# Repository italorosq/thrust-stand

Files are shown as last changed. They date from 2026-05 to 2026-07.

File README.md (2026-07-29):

# thrust-stand




## 📋 Sobre

Sistema embarcado baseado em ESP32 para monitoramento de testes estáticos de motores de foguetes, com aquisição de dados de empuxo e pressão em tempo real, armazenamento em cartão SD e comunicação via Serial/Bluetooth.

## 🚀 Quick Start

1. Clone o repositório

```bash
git clone https://github.com/ViniciusCMB/thrust-stand.git
```

2. Configure o hardware conforme [esquemático](./docs/HARDWARE.md)
3. Carregue o firmware

## 📁 Estrutura do Projeto

```
├── 📂 docs/              # Documentação técnica detalhada
├── 📂 extras/            # Códigos extras utilizados
├── 📂 firmware/          # Código do microcontrolador ESP32
├── 📂 hardware/          # Esquemáticos, PCBs e lista de componentes
├── 📂 software/          # Ferramentas de análise e interface
└── 📂 tests/             # Testes unitários e de integração
```

## 🔧 Pré-requisitos

- Hardware: ESP32 DevKit V1, célula de carga + HX711, sensor de pressão (com divisor resistivo), módulo microSD (SPI), botão tátil (`GPIO33` para TARE), LED com resistor de limitação, buzzer
- Software: Arduino IDE 2.0+
- Bibliotecas: ver `docs/FIRMWARE.md`

## 📖 Documentação

- [Esquemático e Montagem](./docs/HARDWARE.md)
- [Firmware e Arquitetura](./docs/FIRMWARE.md)
- [Protocolos e API](./docs/API.md)
- [Troubleshooting](./docs/TROUBLESHOOTING.md)

## 🎯 Funcionalidades

- ✅ Aquisição de dados de empuxo e pressão em tempo real
- ✅ Armazenamento em cartão SD com arquivos sequenciais
- ✅ Controle local por botões (TARE e novo arquivo)
- ✅ LED de status de gravação no SD
- ✅ Comunicação (Serial, Bluetooth)
- ✅ Calibração persistente da célula de carga

## 📊 Dados de Teste

Os dados de testes estáticos de motores específicos são armazenados no repositório dedicado:
[motor](https://github.com/Serra-Rocketry/motor)

Este repositório (thrust-stand) contém apenas o sistema de aquisição. Os dados coletados durante os testes devem ser commitados no repositório `motor`.

## 🤝 Contribuindo

Este projeto segue as [Boas Práticas da Serra Rocketry](https://github.com/Serra-Rocketry/best-practices). Para contribuir:

1. Fork o projeto
2. Crie uma branch para sua feature (`git checkout -b feature/AmazingFeature`)
3. Commit suas mudanças (`git commit -m 'Add some AmazingFeature'`)
4. Push para a branch (`git push origin feature/AmazingFeature`)
5. Abra um Pull Request

## ✨ Autores

- Equipe Serra Rocketry - Desenvolvimento e documentação
- Contribuidores - [Lista de contribuidores]()

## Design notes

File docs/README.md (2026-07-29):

# 📚 Documentação Técnica - Sistema de Teste Estático

Esta documentação reúne o necessário para montagem, calibração, operação e troubleshooting do sistema baseado em ESP32.

## 🗂️ Estrutura da Documentação

### 1. Guia de Instalação

- Requisitos de hardware e software
- Configuração do ambiente
- Primeira execução

### 2. [Hardware](./HARDWARE.md)

- Lista de componentes (BOM)
- Mapeamento de pinos e conexões
- Função dos botões e do LED

### 3. [Firmware](./FIRMWARE.md)

- Arquitetura e fluxo de aquisição
- Calibração da célula de carga
- Sistema de arquivos e armazenamento

### 4. [API e Protocolos](./API.md)

- Comandos seriais
- Controles físicos
- Exemplos de interação

### 5. [Troubleshooting](./TROUBLESHOOTING.md)

- Problemas comuns e diagnóstico rápido
- Procedimentos de correção

### 6. [Evolução da Caixa](./EVOLUÇÃO_CAIXA.md)

- Histórico das 3 versões da estrutura física
- Comparativo de materiais e design

### 7. [V3 Detalhes](./V3_DETALHES.md)

- Especificações da bancada v3
- Célula de carga, guia linear, resolução

## 📊 Diagramas Técnicos

Arquitetura do sistema:

```
[Sensores] -> [ESP32] -> [Armazenamento] -> [Comunicação]
    |            |             |               |
 Célula/HX711  Process.      microSD        Serial/BT
 Pressão       Dados         Arquivo CSV    Monitoramento
```

Fluxo de dados:

```mermaid
graph TD;
    A[Sensores] --> B[Aquisição];
    B --> C[Processamento];
    C --> D[Armazenamento SD];
    C --> E[Transmissão];
    D --> F[Arquivo CSV];
    E --> G[Serial];
    E --> H[Bluetooth];
```

## 🛠️ Recursos Técnicos

### Especificações do Sistema

- Microcontrolador: ESP32
- Sensores: célula de carga (HX711) e sensor de pressão analógico
- Armazenamento: cartão SD (SPI), com fallback para LittleFS
- Comunicação: Serial USB e Bluetooth
- Controles físicos:
  - Botão `GPIO33`: TARE
  - LED `GPIO19`: aceso durante gravação no SD
  - Buzzer `GPIO32`: sinalização

### Formatos de Dados

- Logs: CSV (`Tempo,Empuxo,Pressao`)
- Configuração: `Preferences` (fator de calibração)
- Comunicação: comandos por texto

## 🤝 Contribuindo para a Documentação

1. Reporte inconsistências encontradas
2. Proponha melhorias de texto e organização
3. Abra PR com correções objetivas

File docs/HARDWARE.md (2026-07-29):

# 🔌 Hardware - Sistema de Teste Estático

## 📋 Visão Geral do Sistema

Sistema embarcado baseado em ESP32 para aquisição de empuxo e pressão em testes estáticos de motores de foguetes, com gravação local de dados no cartão SD e telemetria via Serial/Bluetooth.

Controles físicos do esquemático atual:

- `GPIO33`: botão para TARE (zerar a célula de carga)
- `GPIO19`: LED de indicador de funcionamento (aceso durante gravação no SD)
- `GPIO32`: buzzer de sinalização

## 🧩 Lista de Componentes (BOM)

| Componente | Quantidade | Especificações |
| --- | --- | --- |
| ESP32 DevKit V1 | 1 | 30/38 pinos, WiFi/BT |
| Célula de carga | 1 | Compatível com HX711 |
| Módulo HX711 | 1 | ADC 24 bits para célula de carga |
| Sensor de pressão | 1 | 0-10 MPa, saída analógica 0.5-4.5V |
| Módulo microSD | 1 | Interface SPI |
| LED | 1 | 5mm, vermelho |
| Botão tátil (TARE) | 1 | 6x6mm |
| Buzzer | 1 | Ativo, 5V |
| Resistores do divisor | 2 | 2.2kΩ e 3.3kΩ |
| Resistor do LED | 1 | 220Ω (valor típico) |
| Fonte de alimentação | 1 | 5V 2A (mínimo recomendado) |

## 🔄 Mapeamento de Conexões

| ESP32 | Função no sistema |
| ----- | --- |
| `GPIO4`  | HX711 `DT` |
| `GPIO18` | HX711 `SCK` |
| `GPIO35` | Entrada do sensor de pressão (via divisor resistivo) |
| `GPIO5`  | microSD `CS` |
| `GPIO27` | microSD `MOSI` |
| `GPIO23` | microSD `MISO` |
| `GPIO25` | microSD `SCK` |
| `GPIO19` | LED de gravação |
| `GPIO32` | Buzzer |
| `GPIO33` | Botão TARE |
| `VIN` | Alimentação 5V dos módulos |
| `GND` | Terra comum |

Observações de ligação:

- Botão: um terminal no `GPIO33` e o outro no `GND`.
- LED: ligado ao `GPIO19` com resistor em série.
- Buzzer: ligado ao `GPIO32`.
- Sensor de pressão: saída analógica passa por divisor resistivo antes de chegar ao `GPIO35`.

## 🛠️ Procedimento de Montagem

1. Preparação dos componentes

- Verifique todos os itens da BOM
- Teste ESP32 e cartão SD separadamente antes da montagem final

2. Sequência recomendada

- Conecte alimentação (`VIN` e `GND`)
- Conecte HX711 e célula de carga
- Conecte módulo microSD (SPI)
- Conecte sensor de pressão com divisor resistivo
- Conecte LED de status
- Conecte o botão (`GPIO33`)

3. Divisor resistivo para o sensor de pressão

```
Vsensor (0.5-4.5V) --- R1 (2.2kΩ) --- GPIO35
                         |
                        R2 (3.3kΩ)
                         |
                        GND
```

Cálculo do divisor:

```
Vout = Vsensor * (R2 / (R1 + R2))

# Exemplo
Vout_max = 4.5V * (3300 / (2200 + 3300)) = 2.7V
```

## 📷 Foto de Referência

Montagem completa:

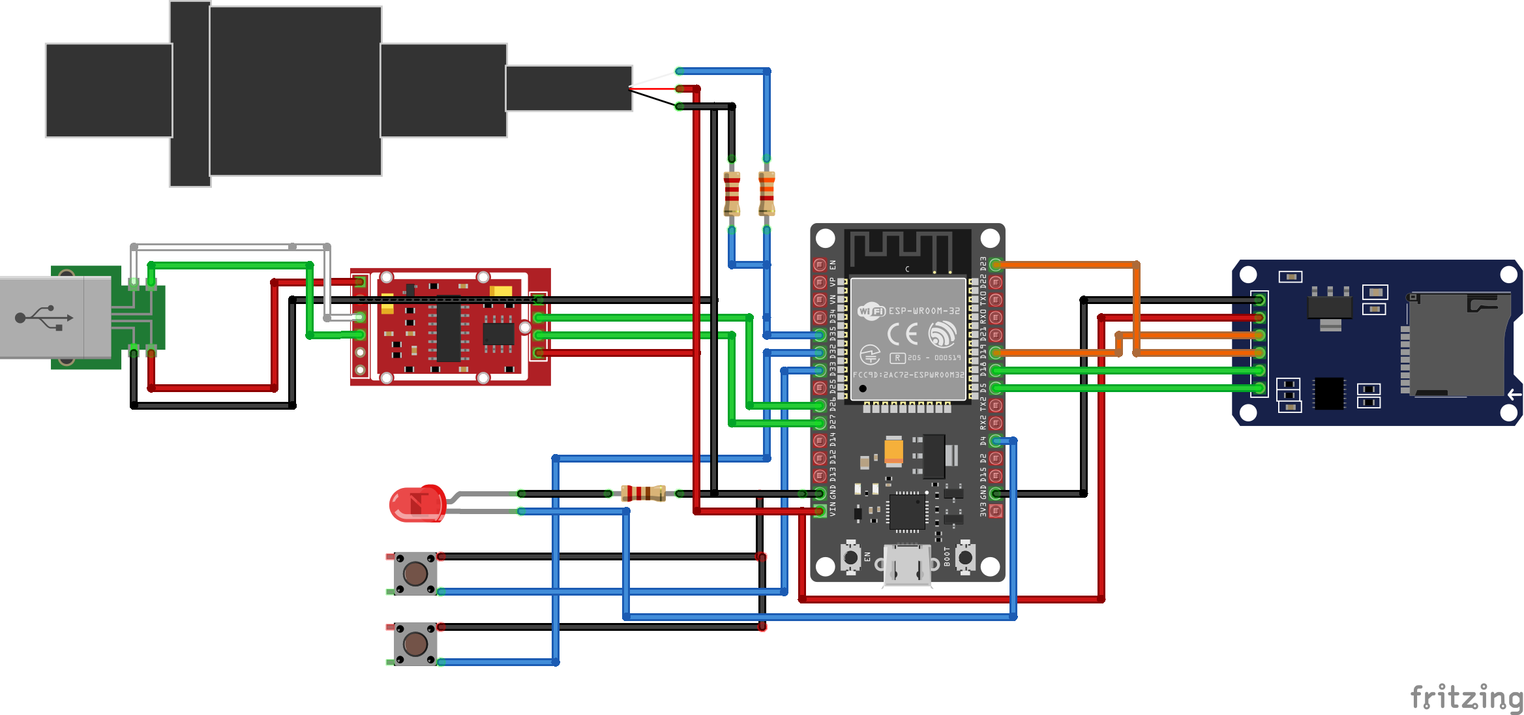
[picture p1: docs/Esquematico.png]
Esquemático


## ⚠️ Considerações de Projeto

- [x] Divisor resistivo no sensor de pressão
- [x] Terra comum entre todos os módulos
- [x] Botão dedicado para TARE
- [x] LED dedicado para indicação de gravação no SD
- [x] Buzzer para sinalização
- [ ] Isolamento contra vibrações
- [ ] Proteção contra poeira e umidade

## 🧪 Testes de Hardware

### Testes pré-montagem

- Continuidade dos cabos
- Tensão de alimentação estável
- Comunicação SPI com microSD
- Leitura de sensores individuais

### Testes pós-montagem

- Botão `GPIO33` realiza TARE
- LED acende durante gravação no SD
- Leituras de empuxo e pressão estáveis

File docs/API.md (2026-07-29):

# 📡 API e Protocolos - Sistema de Teste Estático

## 📋 Visão Geral

Este documento descreve os protocolos de comunicação e as interfaces de controle do sistema de teste estático.

## 🔌 Protocolos Suportados

| Protocolo  | Tipo | Velocidade  | Alcance | Caso de Uso |
| --- | --- | --- | --- | --- |
| Serial USB | Fio | 115200 baud | Local | Configuração, calibração, debug |
| Bluetooth  | Wireless | 115200 baud | ~10 m | Telemetria, comandos, monitoramento |

## 💻 Comunicação Serial/Bluetooth

### Configuração padrão

```
BAUD_RATE = 115200
DATA_BITS = 8
PARITY = NONE
STOP_BITS = 1
FLOW_CONTROL = NONE
```

### Estrutura de comandos

```
COMANDO [PARAMETRO]
```

## 🎮 Comandos Disponíveis

### 1. Modo de configuração (calibração)

```
COMANDO: INIT CONFIG
RESPOSTA: Aguardando fator de carga...
USO: entra no modo de calibração da célula de carga

COMANDO: SET LOAD FACTOR <valor>
EXEMPLO: SET LOAD FACTOR -284.6
RESPOSTA: Fator de carga atualizado
USO: salva o fator de calibração na memória persistente
```

### 2. Controle da célula de carga

```
COMANDO: TARE
RESPOSTA: Célula Zerada!
USO: zera a leitura atual da célula de carga

COMANDO: GET LOAD FACTOR
RESPOSTA: loadFactor atual: <valor>
USO: consulta o fator de calibração atual sem entrar em modo de configuração
```

## 🕹️ Controles Físicos

| Entrada física | Pino ESP32 | Função |
| --- | --- | --- |
| Botão TARE | `GPIO33` | TARE da célula de carga |
| LED | `GPIO19` | Indicador de funcionamento (aceso ao gravar no SD) |
| Buzzer | `GPIO32` | Sinalização sonora |

## 🎯 Exemplo de Interação

### Calibração da célula de carga

```
# Terminal -> ESP32
INIT CONFIG

# ESP32 -> Terminal
Aguardando fator de carga...
# (ESP32 envia leituras RAW continuamente)
152345
152348
152350

# Terminal -> ESP32
SET LOAD FACTOR 277306.0

# ESP32 -> Terminal
Fator de carga atualizado: 277306.00
Modo configuração finalizado
```

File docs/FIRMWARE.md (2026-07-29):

# ⚙️ Firmware - Sistema de Teste Estático

## 🏗️ Arquitetura do Sistema

### Visão Geral

O firmware implementa aquisição contínua de dados para testes estáticos, com leitura da célula de carga e do sensor de pressão, gravação em cartão SD e transmissão de logs via Serial/Bluetooth.

### Diagrama de Arquitetura

```
┌─────────────────┐    ┌──────────────────┐    ┌──────────────────┐
│   SENSORES      │    │    PROCESSAMENTO │    │     SAÍDAS       │
│                 │    │                  │    │                  │
│  Célula Carga   │───▶│   Aquisição      │───▶│  Cartão SD       │
│  Sensor Pressão │    │   Filtragem      │    │  Serial USB      │
│                 │    │   Formatação CSV │    │  Bluetooth       │
└─────────────────┘    └──────────────────┘    └──────────────────┘
         │                        │                        │
         └────────────────────────┼────────────────────────┘
                                  │
                         ┌──────────────────┐
                         │   CONTROLE       │
                         │                  │
                         │  Botão TARE      │
                         │  Novo arquivo    │
                         │  Estado do LED   │
                         └──────────────────┘
```

## 📁 Estrutura de Código

### Módulos Principais

```
firmware/
├── 📄 firmware.ino              # Arquivo principal
└── 📄 Pressure.h                # Classe sensor de pressão
```

### Dependências e Bibliotecas

- Wire
- HX711
- FS
- SD
- LittleFS
- SPI
- Pushbutton
- BluetoothSerial
- Preferences

Obs.: instale as bibliotecas acima no ambiente Arduino/PlatformIO.

## 🔧 Configuração e Calibração

### Preferências Persistentes

O sistema usa `Preferences` para salvar o fator de calibração da célula de carga.

```cpp
// Carregar configuração
loadFactor = preferences.getFloat("loadFactor", -284.6);

// Salvar configuração
preferences.putFloat("loadFactor", loadFactor);
```

## 🔄 Fluxo de Execução

1. Inicialização (`setup()`)

```cpp
void setup() {
    Serial.begin(115200);
    SerialBT.begin("ESP32_BT");

    preferences.begin("app", false);
    loadFactor = preferences.getFloat("loadFactor", -284.6);

    pressureSensor.begin();

    setupStorageAndFile();
    setupHX711();
}
```

2. Loop principal (`loop()`)

```cpp
void loop() {
    staticTest();  // coleta e log periódico

    // Botão 1: TARE da célula de carga
    // Botão 2: iniciar novo arquivo de log

    if (Serial.available()) {
        // comandos de calibração e controle
    }
}
```

## 📊 Aquisição de Dados

### Estrutura registrada

```csv
Tempo,Empuxo,Pressao
0,0.000000,0.000000
100,1.234567,1.902000
200,2.345678,1.955000
```

### Processo de log

- Leitura da célula de carga (`HX711`)
- Leitura do sensor de pressão (`PressureSensor`)
- Atualização de picos de leitura
- Escrita no arquivo CSV atual no SD/LittleFS
- Espelhamento da leitura em Serial/Bluetooth

## 🎮 Controle do Sistema

### Interface Serial/Bluetooth

Os comandos podem ser enviados pela Serial USB ou pela Bluetooth Serial. Ambas as interfaces recebem e respondem comandos.

### Comandos disponíveis

| Comando | Descrição | Exemplo | Resposta esperada |
| --- | --- | --- | --- |
| INIT CONFIG | Entra em modo calibração | `INIT CONFIG` | Aguarda fator de carga |
| SET LOAD FACTOR | Define fator de carga | `SET LOAD FACTOR -284.6` | Fator atualizado |
| GET LOAD FACTOR | Consulta fator atual | `GET LOAD FACTOR` | loadFactor atual: valor  |
| TARE | Zera célula de carga | `TARE` | Célula zerada |

### Entradas físicas

- Botão em `GPIO33`: executa TARE da célula de carga
- LED em `GPIO19`: aceso durante gravação no cartão SD
- Buzzer em `GPIO32`: sinalização sonora

## 💾 Sistema de Arquivos

### Estratégia de armazenamento

- O firmware tenta inicializar o cartão SD
- Em falha do SD, usa LittleFS como fallback
- Arquivos são gerados em sequência (`Dados_001.txt`, `Dados_002.txt`, ...)

### Formato do arquivo de dados

```csv
Tempo,Empuxo,Pressao
0,0.000000,0.000000
100,1.234567,1.902000
```

## 📡 Comunicação

- Serial USB: configuração, calibração e debug
- Bluetooth: espelhamento de leituras/estado

## 🚀 Compilação e Upload

### Arduino IDE

1. Selecione a placa `ESP32 Dev Module`
2. Configure a porta serial correta
3. Verifique as bibliotecas instaladas
4. Compile e faça upload

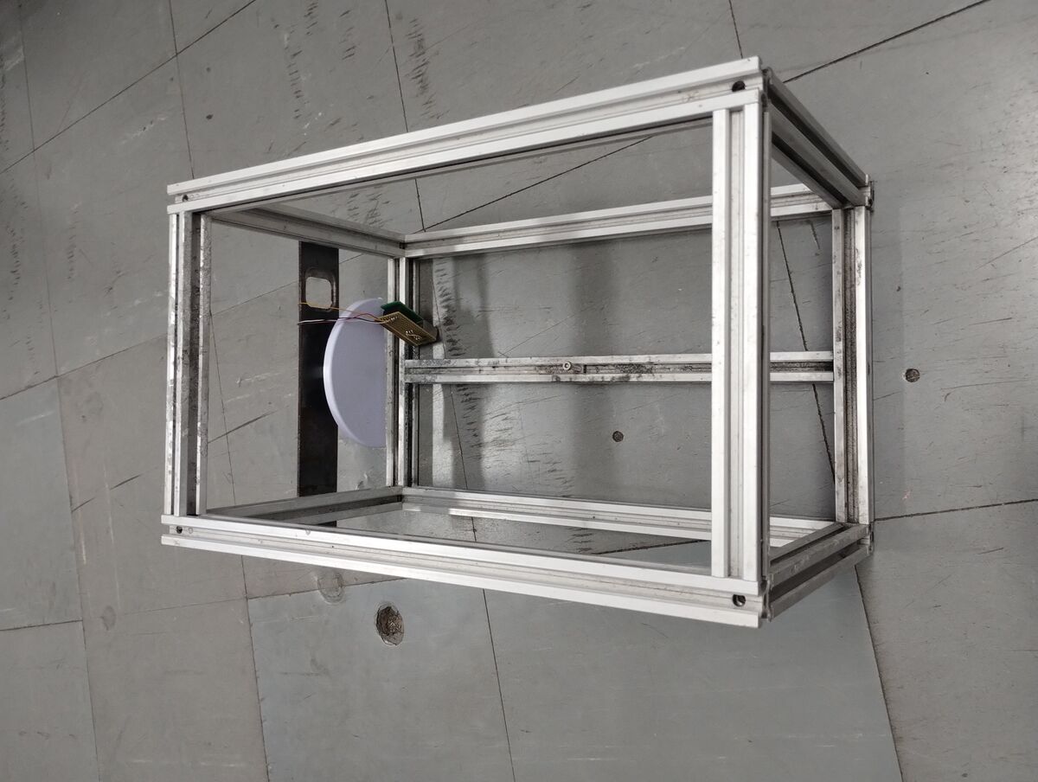
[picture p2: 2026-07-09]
docs/imagens/caixa_v1_frontal_superior.jpg

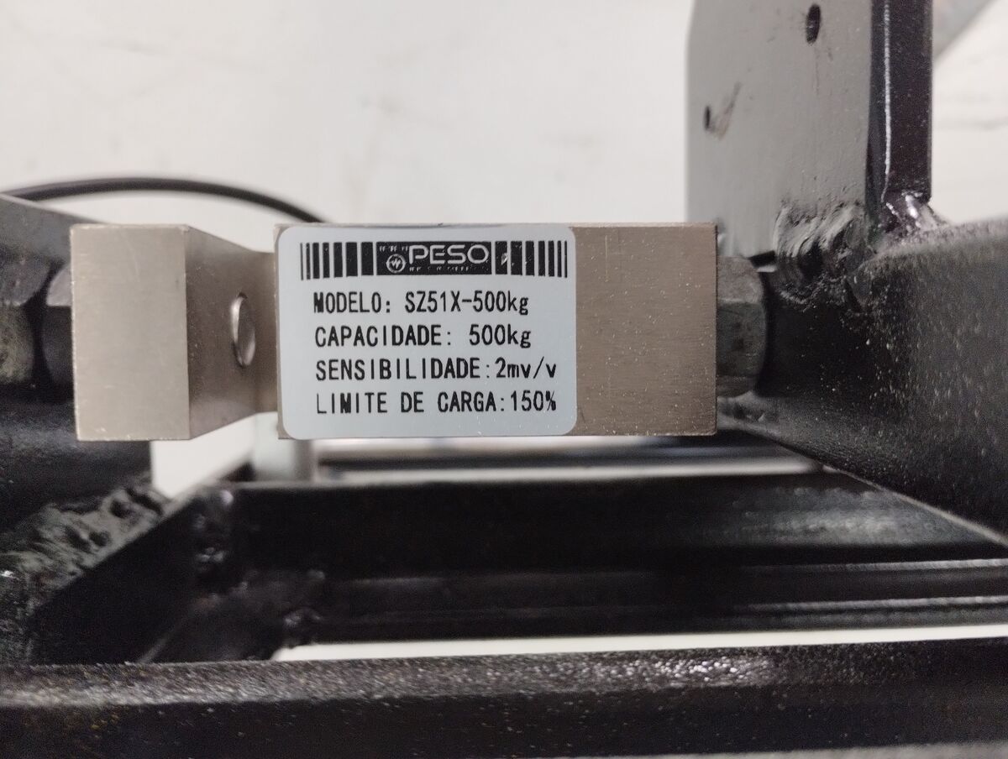
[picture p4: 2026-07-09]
docs/imagens/v3_celula_carga.jpg

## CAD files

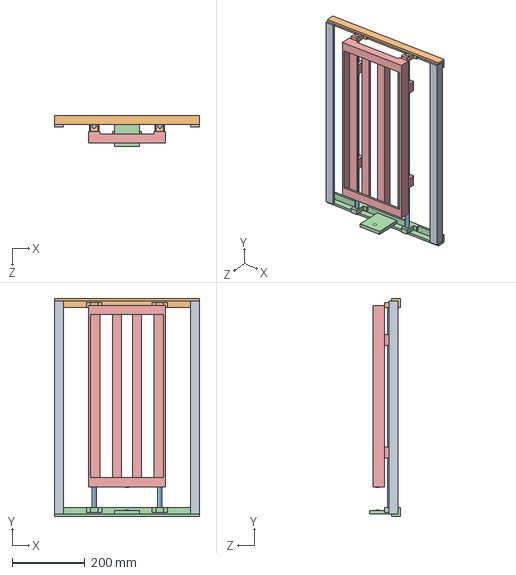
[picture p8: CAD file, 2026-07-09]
hardware/teste_estatico/step/caixa_v3.step
400.0 x 600.0 x 85.5 mm
Caixa_Teste_Estático_Basev3
Caixa_Teste_Estático_carrinhov3

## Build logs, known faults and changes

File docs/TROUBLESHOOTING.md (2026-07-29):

# 🐛 Troubleshooting - Sistema de Teste Estático

## 📋 Visão Geral

Guia rápido para diagnosticar falhas de alimentação, gravação no SD, leitura de sensores e controle por botões.

## 🔍 Diagnóstico Rápido

### LED de funcionamento (`GPIO19`)

| Estado do LED | Significado | Ação |
| --- | --- | ---- |
| Aceso | Sistema gravando no SD | Operação normal |
| Apagado durante gravação esperada | Sem escrita no arquivo atual | Verificar SD e fluxo de gravação |

### Botão TARE

| Botão | Pino | Função esperada |
| ----- | ---- | --- |
| Botão TARE | `GPIO33` | TARE da célula de carga |

## 🚨 Problemas Comuns e Soluções

### 1. 🔌 Problemas de alimentação

Sintomas:

- Sistema não liga
- Reinicializações aleatórias
- Leituras instáveis

Soluções:

```
1. Medir 5V em VIN e 3.3V no ESP32
2. Confirmar fonte com corrente suficiente (>= 2A recomendado)
3. Testar com outro cabo USB/fonte
4. Confirmar GND comum entre todos os módulos
```

### 2. 💾 Problemas com cartão SD

Sintomas:

- Falha ao iniciar armazenamento
- Arquivo não é criado
- LED não acende quando deveria gravar

Soluções:

```
1. Verificar formatação FAT32
2. Verificar conexões SPI: CS(5), MOSI(27), MISO(23), SCK(25)
3. Testar outro cartão SD
4. Verificar alimentação e GND do módulo SD
```

### 3. ⚖️ Problemas com célula de carga / HX711

Sintomas:

- Leitura travada em valor fixo
- Leitura muito ruidosa
- TARE não zera

Soluções:

```
1. Verificar DT(GPIO4) e SCK(GPIO18)
2. Verificar ligação da célula no HX711
3. Executar TARE pelo botão GPIO33 e por comando serial (TARE)
4. Repetir calibração com peso conhecido
```

### 4. 📊 Problemas com sensor de pressão

Sintomas:

- Leitura em 0 constante
- Saturação em valor máximo
- Oscilação elevada

Soluções:

```
1. Verificar alimentação do sensor
2. Verificar divisor resistivo (2.2kΩ e 3.3kΩ)
3. Medir tensão no GPIO35 (faixa esperada: 0-3.3V)
4. Conferir GND comum entre sensor e ESP32
```

### 5. 🎛️ Problemas nos botões

Sintomas:

- Botão de TARE não responde

Soluções:

```
1. Conferir ligação dos botões para GND
2. Conferir pino correto: GPIO33 (TARE)
3. Verificar mau contato no botão/chicote
4. Testar acionamento com monitor serial aberto
```

### 6. 📡 Problemas de comunicação Serial/Bluetooth

Sintomas:

- Sem dados no terminal serial
- Bluetooth não encontra o dispositivo

Soluções:

```
1. Confirmar baud rate 115200
2. Testar outro cabo USB
3. Confirmar porta serial correta
4. Reiniciar ESP32 e reconectar Bluetooth
```

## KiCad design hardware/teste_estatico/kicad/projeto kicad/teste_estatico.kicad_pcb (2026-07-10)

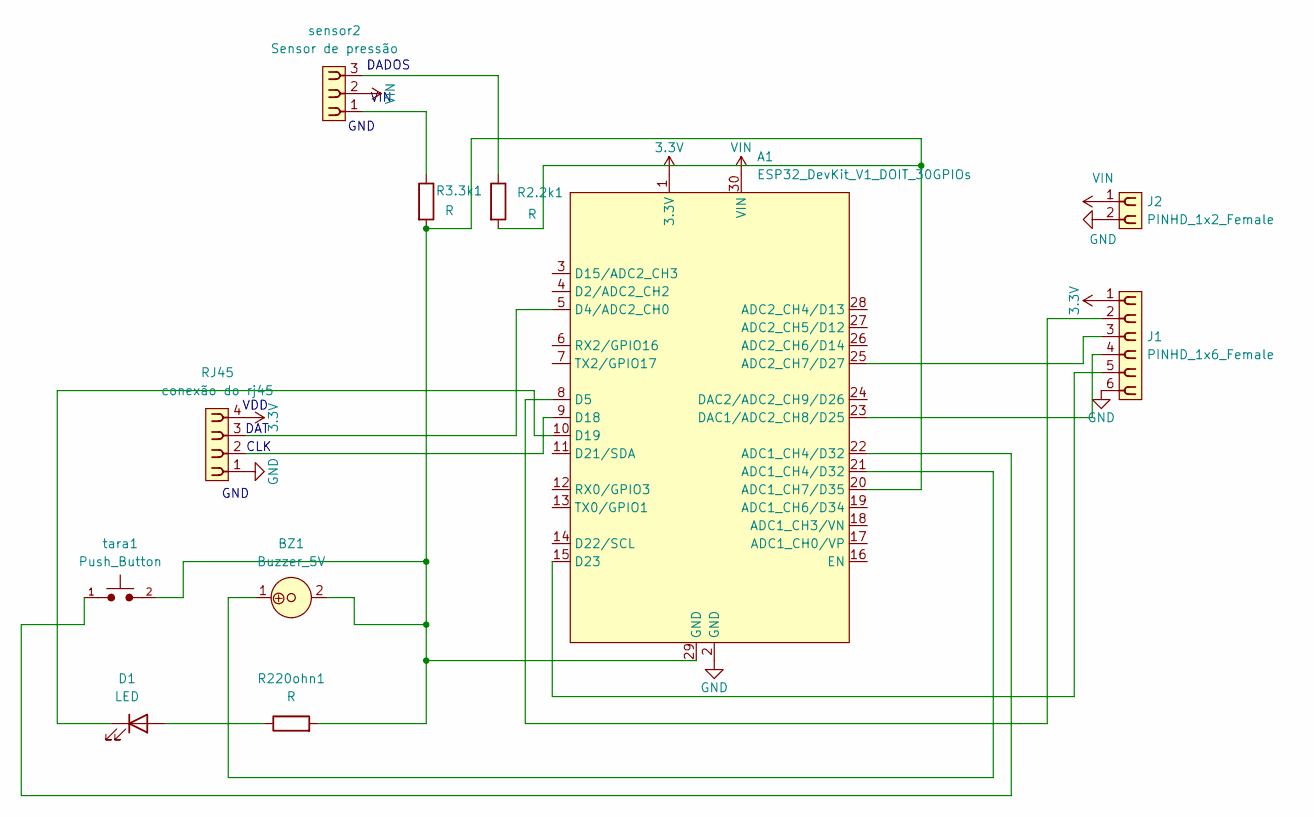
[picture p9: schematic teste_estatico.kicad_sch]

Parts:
A1: ESP32_DevKit_V1_DOIT_30GPIOs; DOIT_ESP32_DEVKIT_30Pins
BZ1: Buzzer_5V; MagneticBuzzer_ProSignal_ABT-410-RC
D1: LED; LED_D5.0mm_FlatTop
J1: PINHD_1x6_Female; PinSocket_1x06_P2.54mm_Vertical
J2: PINHD_1x2_Female; PinSocket_1x02_P2.54mm_Vertical
R2.2k1, R3.3k1, R220ohn1: R; R_Axial_DIN0309_L9.0mm_D3.2mm_P12.70mm_Horizontal
RJ45: conexão do rj45; PinSocket_1x04_P2.54mm_Vertical
sensor2: Sensor de pressão; PinSocket_1x03_P2.54mm_Vertical
tara1: Push_Button; SW_PUSH_6mm

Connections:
3.3V: A1.1 (3.3V), J1.1, RJ45.4
GND: A1.2 (GND), J1.6, J2.2, RJ45.1
unnamed: A1.21 (ADC1_CH4/D32), BZ1.1
unnamed: A1.22 (ADC1_CH4/D32), tara1.1
unnamed: A1.20 (ADC1_CH7/D35), A1.29 (GND), BZ1.2, R2.2k1.2, R3.3k1.2, R220ohn1.2, tara1.2
unnamed: A1.25 (ADC2_CH7/D27), J1.3
unnamed: A1.5 (D4/ADC2_CH0), RJ45.3
unnamed: A1.8 (D5), J1.2
unnamed: A1.9 (D18), RJ45.2
unnamed: A1.10 (D19), D1.1 (K)
unnamed: A1.15 (D23), J1.5
unnamed: A1.23 (DAC1/ADC2_CH8/D25), J1.4
unnamed: D1.2 (A), R220ohn1.1
unnamed: R2.2k1.1, sensor2.3
unnamed: R3.3k1.1, sensor2.1
VIN: A1.30 (VIN), J2.1, sensor2.2

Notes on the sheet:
DADOS
DAT
GND
CLK
VIN
VDD

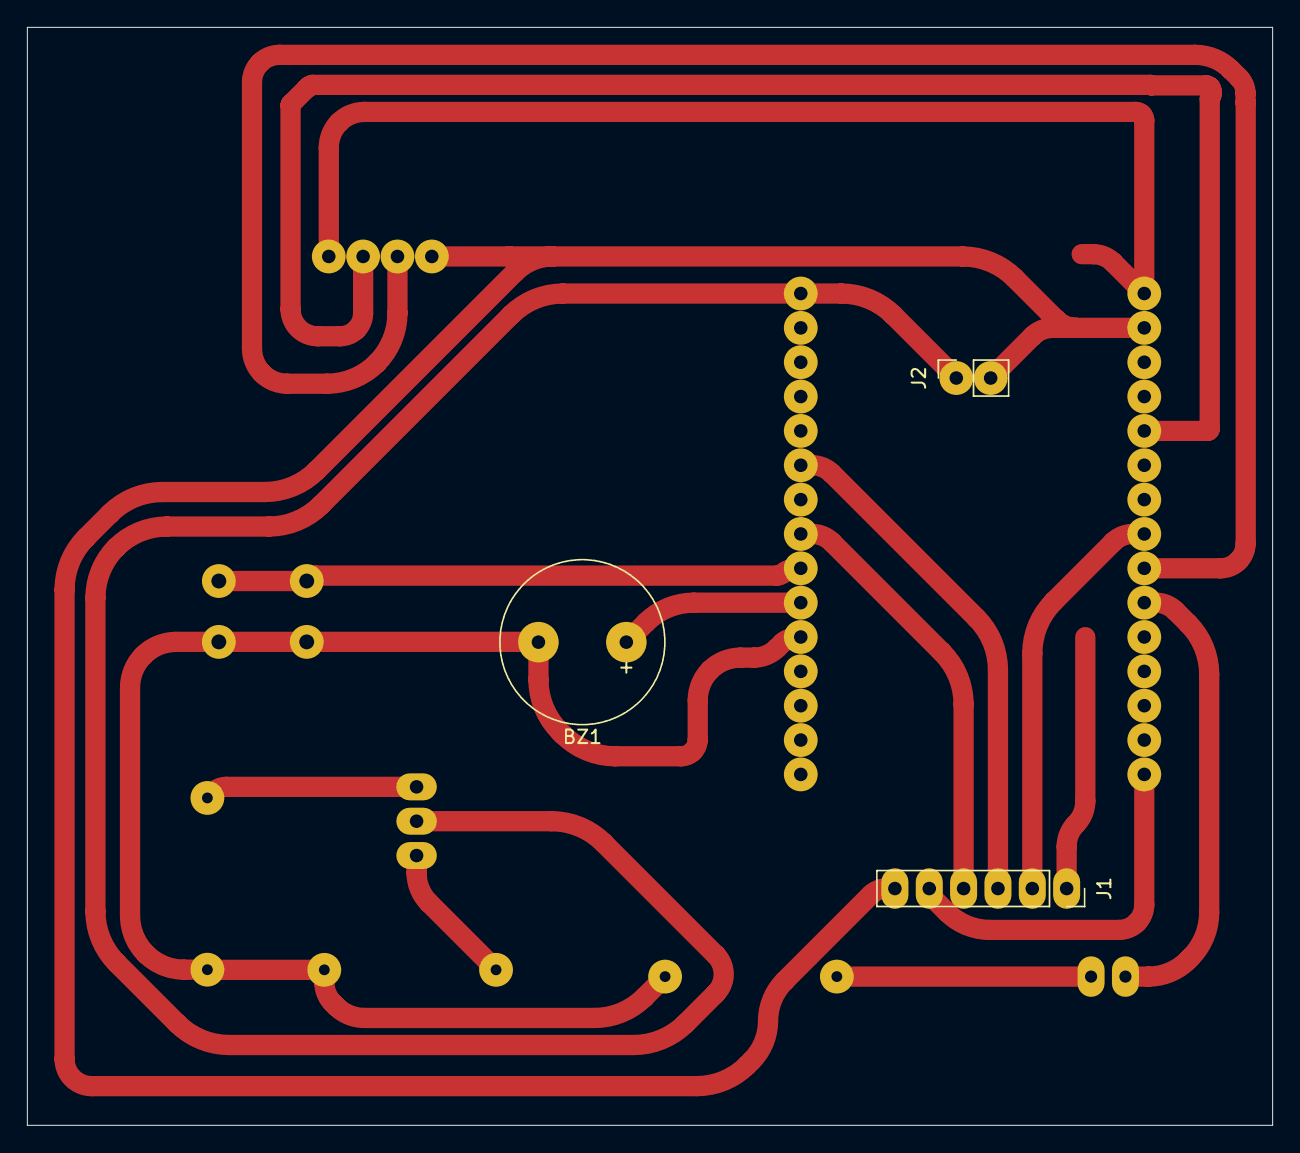
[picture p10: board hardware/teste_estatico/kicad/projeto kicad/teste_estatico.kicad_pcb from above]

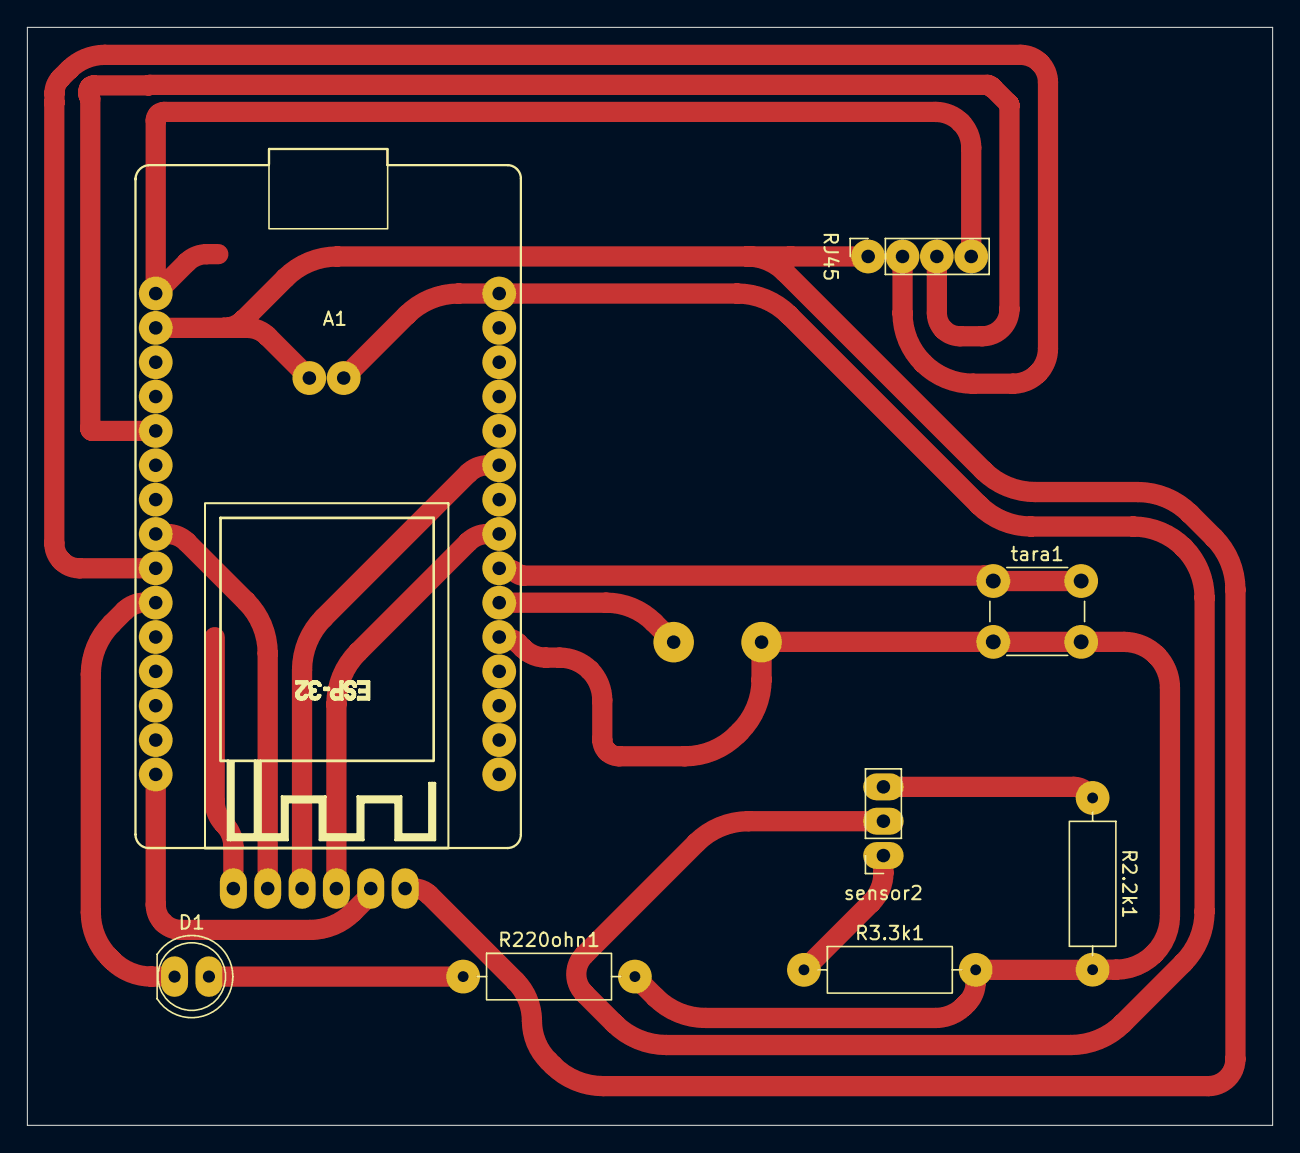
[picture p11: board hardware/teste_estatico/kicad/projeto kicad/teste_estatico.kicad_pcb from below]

Board: 2 copper layers, 92.1 x 81.2 mm, 11 parts (8 on the bottom side), 16 nets.

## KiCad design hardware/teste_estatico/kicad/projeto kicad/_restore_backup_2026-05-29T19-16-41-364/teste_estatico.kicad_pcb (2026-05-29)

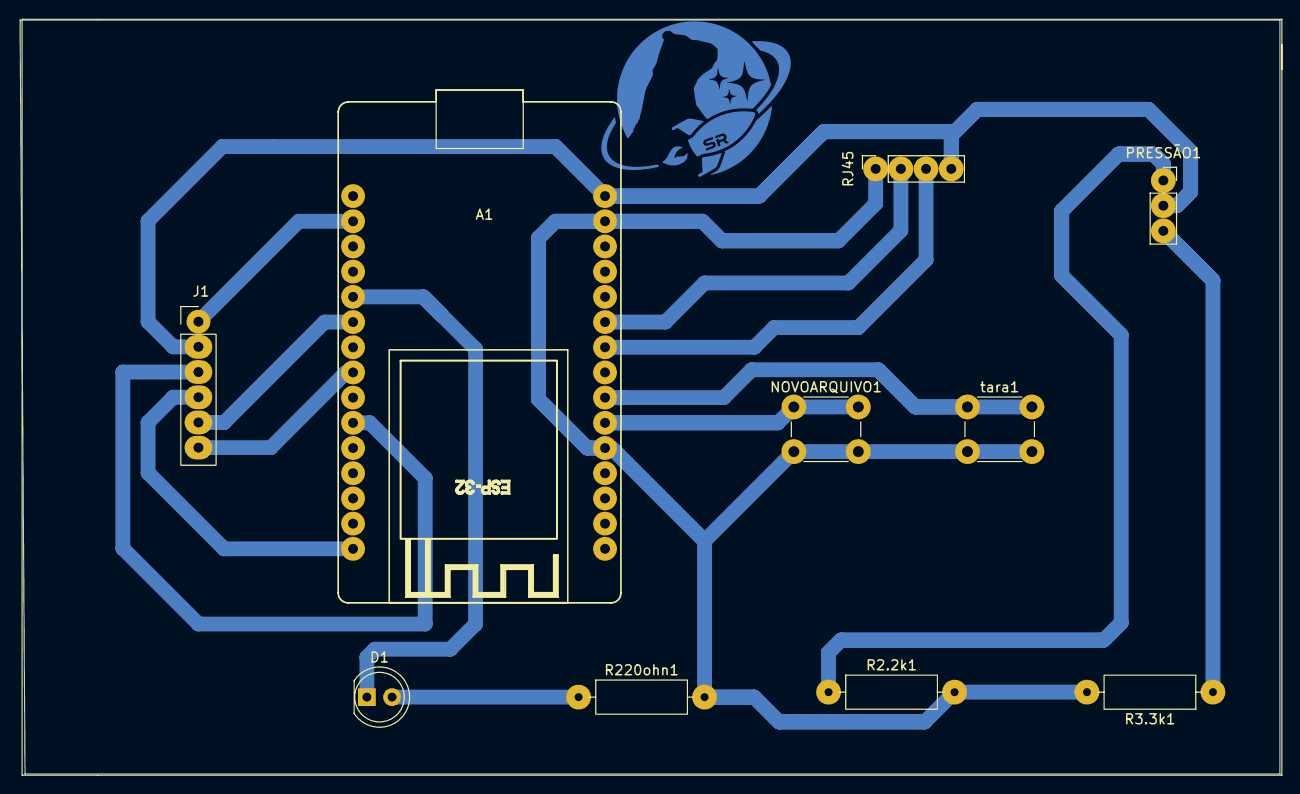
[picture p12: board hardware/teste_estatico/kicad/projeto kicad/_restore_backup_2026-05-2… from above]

Board: 2 copper layers, 127.0 x 76.0 mm, 10 parts (0 on the bottom side), 14 nets.

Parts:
A1: ESP32_DevKit_V1_DOIT_30GPIOs; DOIT_ESP32_DEVKIT_30Pins
D1: LED; LED_D5.0mm_FlatTop
J1: PINHD_1x6_Female; PinSocket_1x06_P2.54mm_Vertical
NOVOARQUIVO1: Push_Button; SW_PUSH_6mm
PRESSÃO1: Sensor de pressão; PinSocket_1x03_P2.54mm_Vertical
R2.2k1, R3.3k1, R220ohn1: R; R_Axial_DIN0309_L9.0mm_D3.2mm_P12.70mm_Horizontal
RJ45: conexão do rj45; PinSocket_1x04_P2.54mm_Vertical
tara1: Push_Button; SW_PUSH_6mm

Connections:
unnamed: A1.21 (ADC1_CH4/D32), NOVOARQUIVO1.1
unnamed: A1.22 (ADC1_CH4/D32), tara1.1
unnamed: A1.20 (ADC1_CH7/D35), A1.29 (GND), NOVOARQUIVO1.2, R2.2k1.2, R3.3k1.2, R220ohn1.2, RJ45.1, tara1.2
unnamed: A1.25 (ADC2_CH7/D27), RJ45.2
unnamed: A1.5 (D4/ADC2_CH0), D1.1 (K)
unnamed: A1.8 (D5), J1.6
unnamed: A1.10 (D19), J1.3
unnamed: A1.15 (D23), J1.4
unnamed: A1.24 (DAC2/ADC2_CH9/D26), RJ45.3
unnamed: A1.2 (GND), J1.1
unnamed: A1.6 (RX2/GPIO16), J1.5
unnamed: A1.30 (VIN), J1.2, PRESSÃO1.2, RJ45.4
unnamed: D1.2 (A), R220ohn1.1
unnamed: PRESSÃO1.1, R2.2k1.1

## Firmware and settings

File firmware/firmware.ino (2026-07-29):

// INCLUSÃO DE BIBLIOTECAS
#include <HX711.h>
#include <FS.h>
#include <SD.h>
#include <LittleFS.h>
#include <SPI.h>
#include <Pushbutton.h>
#include <BluetoothSerial.h>
#include <Preferences.h>

#include "Pressure.h"

// Definições de pinos e constantes
#define LED_PIN 19        // Pino do LED
#define CS_PIN 5          // Pino do cartão SD (CS)
#define SD_SCK_PIN 25     // Pino SCK do SD
#define SD_MISO_PIN 23    // Pino MISO do SD
#define SD_MOSI_PIN 27    // Pino MOSI do SD
#define BUZZER_PIN 32     // Pino do buzzer
#define BTN_PIN 33        // Pino do botão
#define CELULA_DT_PIN 4   // Pino de dados da célula de carga (DAT)
#define CELULA_SCK_PIN 18 // Pino de clock da célula de carga (CLK)
#define PRESSURE_PIN 35   // Pino do sensor de pressão
#define INTERVALO 1       // Intervalo de leitura em milissegundos

// Instância SPI customizada para o SD (SCK=25, MISO=23, MOSI=27, CS=5)
SPIClass spiSD(VSPI);

// Variáveis globais
const float VinPressure = 5.0;    // Tensão que alimenta o sensor
const float VminPressure = 0.27;  // Tensão de saída em 0 MPa
const float VmaxPressure = 4.5;   // Tensão de saída em 10 MPa
const float maxPressure = 10.0;   // Pressão máxima do sensor em MPa
const float R1 = 2200.0;          // Resistor entre sensor e pino ESP32
const float R2 = 3300.0;          // Resistor entre pino ESP32 e GND
const int RESOLUCAO_ADC = 4095;   // ESP32 tem ADC de 12 bits (2^12 - 1)
const float TENSAO_MAX_ADC = 3.3; // Tensão de referência do ADC do ESP32
float maxValues[2] = {0.0, 0.0};  // Leituras de pico (peso, pressão)
unsigned long previousMillis = 0; // Controle de tempo
float loadFactor = 0.0;           // Fator de calibração
String filedir = "";              // Caminho do arquivo
String leitura = "";              // Leitura dos dados

enum StorageType { STORAGE_NONE, STORAGE_SD, STORAGE_LITTLEFS };
StorageType storageType = STORAGE_NONE;

static bool configMode = false;

// Instanciação de objetos
Pushbutton button(BTN_PIN);
PressureSensor pressureSensor(PRESSURE_PIN, R1, R2, RESOLUCAO_ADC, TENSAO_MAX_ADC, VminPressure, VmaxPressure, maxPressure);
HX711 escala;
BluetoothSerial SerialBT;
Preferences preferences;

// Declarações antecipadas
void processCommand(String command);
void setLoadFactor(float factor);
void buzzSignal(String signal);
bool setupStorage();
bool setupStorageAndFile();
bool setupHX711();
void logData(unsigned long ms);
bool writeFile(const String &path, const String &message);
void appendFile(const String &path, const String &message);
void printToSerials(const String &message);
void staticTest();
String generateFileName();

void setup()
{
  Serial.begin(115200);
  SerialBT.begin("ESP32_BT");

  preferences.begin("app", false);
  loadFactor = preferences.getFloat("loadFactor", -284.6);

  Serial.println("=== BOOT ===");
  printToSerials("loadFactor carregado: " + String(loadFactor, 4));

  pinMode(LED_PIN, OUTPUT);
  pinMode(BUZZER_PIN, OUTPUT);
  pinMode(BTN_PIN, INPUT);

  pressureSensor.begin();

  bool sdOk = setupStorageAndFile();
  bool hx711Ok = setupHX711();

  if (sdOk && hx711Ok)
  {
    printToSerials("Sistema configurado. Transmitindo...");
    buzzSignal("Sucesso");
  }
  else
  {
    if (!sdOk)   printToSerials("ERRO: Falha no storage.");
    if (!hx711Ok) printToSerials("ERRO: Falha no HX711.");
    printToSerials("Falha critica. Reiniciando...");
    buzzSignal("Alerta");
    delay(3000);
    ESP.restart();
  }
}

void loop()
{
  if (!configMode)
  {
    staticTest();
  }

  if (button.getSingleDebouncedPress())
  {
    if (escala.wait_ready_timeout(1000))
    {
      buzzSignal("Beep");
      printToSerials("Celula Zerada!");
      escala.tare();
    }
    else
    {
      printToSerials("HX711 nao pronto, TARE ignorado.");
    }
  }

  if (Serial.available())
  {
    String command = Serial.readStringUntil('\n');
    command.trim();
    processCommand(command);
  }

  if (SerialBT.available())
  {
    String command = SerialBT.readStringUntil('\n');
    command.trim();
    processCommand(command);
  }

  // Stream RAW de calibração
  if (configMode)
  {
    if (escala.wait_ready_timeout(1000))
    {
      long raw = escala.get_value(1);
      Serial.println(raw);
      SerialBT.println(raw);
    }
    delay(200);
  }
}

void processCommand(String command)
{
  if (command.equalsIgnoreCase("TARE"))
  {
    if (escala.wait_ready_timeout(1000))
    {
      buzzSignal("Beep");
      printToSerials("Celula Zerada!");
      escala.tare();
    }
    else
    {
      printToSerials("HX711 nao pronto, TARE ignorado.");
    }
    return;
  }

  if (command.equalsIgnoreCase("GET LOAD FACTOR"))
  {
    printToSerials("loadFactor atual: " + String(loadFactor, 4));
    return;
  }

  if (command.startsWith("INIT CONFIG"))
  {
    if (escala.wait_ready_timeout(1000))
    {
      escala.tare();
      configMode = true;
      printToSerials("Modo calibracao ativo. Aguardando SET LOAD FACTOR...");
    }
    else
    {
      printToSerials("HX711 nao pronto. Verifique conexoes.");
    }
    return;
  }

  if (configMode && command.startsWith("SET LOAD FACTOR"))
  {
    int lastSpaceIndex = command.lastIndexOf(' ');
    if (lastSpaceIndex != -1)
    {
      String factorStr = command.substring(lastSpaceIndex + 1);
      float factor = factorStr.toFloat();
      if (!isnan(factor) && factor != 0.0)
      {
        setLoadFactor(factor);
        configMode = false;
        printToSerials("Modo calibracao finalizado.");
      }
      else
      {
        printToSerials("Valor invalido. Tente novamente.");
        buzzSignal("Alerta");
      }
    }
    return;
  }
}

void setLoadFactor(float factor)
{
  loadFactor = factor;
  escala.set_scale(loadFactor);
  preferences.putFloat("loadFactor", loadFactor);
  printToSerials("Fator de carga atualizado: " + String(loadFactor, 4));
  buzzSignal("Sucesso");
}

void buzzSignal(String signal)
{
  int frequency = 1000;
  if (signal == "Alerta")
  {
    for (int i = 0; i < 5; i++)
    {
      tone(BUZZER_PIN, frequency, 200);
      delay(350);
    }
  }
  else if (signal == "Sucesso")
  {
    for (int i = 0; i < 3; i++)
    {
      tone(BUZZER_PIN, frequency, 100);
      delay(200);
    }
  }
  else if (signal == "Ativado")
  {
    tone(BUZZER_PIN, frequency, 500);
  }
  else if (signal == "Beep")
  {
    tone(BUZZER_PIN, frequency, 50);
  }
  else
  {
    Serial.println("Sinal invalido!");
  }
}

String generateFileName()
{
  const char* prefix = (storageType == STORAGE_SD) ? "Dados" : "dados";

  for (int i = 1; i <= 999; i++)
  {
    char candidate[32];
    snprintf(candidate, sizeof(candidate), "/%s_%03d.txt", prefix, i);

    bool exists = false;
    if (storageType == STORAGE_SD) {
      exists = SD.exists(candidate);
    } else if (storageType == STORAGE_LITTLEFS) {
      exists = LittleFS.exists(candidate);
    }

    if (!exists)
      return String(candidate);
  }

  return "/overflow.txt";
}

bool setupStorage()
{
  Serial.println("Inicializando SD...");
  spiSD.begin(SD_SCK_PIN, SD_MISO_PIN, SD_MOSI_PIN, CS_PIN);
  delay(100); // aguarda estabilização do SPI

  if (SD.begin(CS_PIN, spiSD) && SD.cardType() != CARD_NONE)
  {
    storageType = STORAGE_SD;
    Serial.println("SD iniciado!");
    Serial.printf("Tipo: %s\n",
      SD.cardType() == CARD_MMC  ? "MMC"  :
      SD.cardType() == CARD_SD   ? "SDSC" :
      SD.cardType() == CARD_SDHC ? "SDHC" : "UNKNOWN");
    return true;
  }

  Serial.println("SD falhou. Tentando LittleFS...");
  yield();

  if (LittleFS.begin(true))
  {
    storageType = STORAGE_LITTLEFS;
    Serial.println("LittleFS iniciado!");
    Serial.printf("Total: %u bytes, Usado: %u bytes\n",
      (unsigned)LittleFS.totalBytes(), (unsigned)LittleFS.usedBytes());
    return true;
  }

  Serial.println("ERRO: Nenhum storage disponivel!");
  return false;
}

bool setupStorageAndFile()
{
  if (!setupStorage())
    return false;

  filedir = generateFileName();
  Serial.print("Arquivo: ");
  Serial.println(filedir);

  if (!writeFile(filedir, "Tempo,Empuxo,Pressao\n"))
  {
    printToSerials("Falha ao criar arquivo");
    return false;
  }

  printToSerials("Arquivo criado: " + filedir);
  return true;
}

bool setupHX711()
{
  Serial.println("Iniciando HX711...");
  escala.begin(CELULA_DT_PIN, CELULA_SCK_PIN);

  unsigned long timeout = millis();
  while (!escala.is_ready())
  {
    if (millis() - timeout > 5000)
    {
      Serial.println("ERRO: HX711 nao respondeu (timeout 5s). Verifique DT=4, SCK=18.");
      return false;
    }
    delay(10);
  }

  Serial.println("HX711 detectado OK.");
  escala.set_scale(loadFactor);
  Serial.print("set_scale com fator: ");
  Serial.println(loadFactor, 4);

  // Warmup: descarta as primeiras leituras para estabilizar
  Serial.println("Aguardando estabilizacao...");
  for (int i = 0; i < 10; i++)
  {
    escala.get_value(1);
    delay(100);
  }

  escala.tare(10); // média de 10 amostras para tara precisa
  Serial.println("tare OK");

  printToSerials("HX711 conectado");
  return true;
}

void logData(unsigned long ms)
{
  if (!escala.wait_ready_timeout(1000))
  {
    Serial.println("AVISO: HX711 timeout em logData, pulando leitura.");
    return;
  }

  float peso = abs(escala.get_units(1)); // 1 amostra por leitura
  float pressao = pressureSensor.readMPa();

  if (peso > maxValues[0]) maxValues[0] = peso;
  if (pressao > maxValues[1]) maxValues[1] = pressao;

  leitura = String(ms) + "," + String(peso, 6) + "," + String(pressao, 6);

  printToSerials(leitura);
  appendFile(filedir, leitura);
}

bool writeFile(const String &path, const String &message)
{
  File file;

  if (storageType == STORAGE_SD) {
    file = SD.open(path, FILE_WRITE);
  } else if (storageType == STORAGE_LITTLEFS) {
    file = LittleFS.open(path, FILE_WRITE);
  } else {
    return false;
  }

  if (!file)
  {
    printToSerials("Falha ao abrir arquivo para escrita: " + path);
    return false;
  }

  bool ok = file.print(message);
  file.close();

  if (ok)
  {
    digitalWrite(LED_PIN, HIGH);
    Serial.println("SD: arquivo criado OK");
  }
  else
  {
    printToSerials("Falha ao escrever no arquivo");
    digitalWrite(LED_PIN, LOW);
  }

  return ok;
}

void appendFile(const String &path, const String &message)
{
  File file;

  if (storageType == STORAGE_SD) {
    file = SD.open(path, FILE_APPEND);
  } else if (storageType == STORAGE_LITTLEFS) {
    file = LittleFS.open(path, FILE_APPEND);
  } else {
    Serial.println("ERRO: storage nao inicializado em appendFile");
    return;
  }

  if (!file)
  {
    printToSerials("Falha ao abrir arquivo para append: " + path);
    return;
  }

  bool ok = file.print(message + "\n");
  file.close();

  if (ok)
  {
    digitalWrite(LED_PIN, HIGH);
  }
  else 
  {
    printToSerials("Falha ao gravar linha no arquivo");
    digitalWrite(LED_PIN, LOW);
  }
}

void printToSerials(const String &message)
{
  Serial.println(message);
  SerialBT.println(message);
}

void staticTest()
{
  unsigned long currentMillis = millis();
  if (currentMillis - previousMillis >= INTERVALO)
  {
    previousMillis = currentMillis;
    logData(currentMillis);
  }
}

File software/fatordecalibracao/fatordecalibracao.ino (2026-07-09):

#include "HX711.h"
#include "BluetoothSerial.h"

const int LOADCELL_DOUT_PIN = 26;
const int LOADCELL_SCK_PIN = 27;

HX711 scale;
BluetoothSerial SerialBT;
float calibration_factor = 100.0;

void printBoth(String msg) {
  Serial.println(msg);
  SerialBT.println(msg);
}

void processCommand(char cmd) {
  switch (cmd) {
    case 'A': calibration_factor += 100.0; scale.set_scale(calibration_factor); break;
    case 'Z': calibration_factor -= 100.0; scale.set_scale(calibration_factor); break;
    case 'a': calibration_factor += 10.0;  scale.set_scale(calibration_factor); break;
    case 'z': calibration_factor -= 10.0;  scale.set_scale(calibration_factor); break;
    case 's': calibration_factor += 1.0;   scale.set_scale(calibration_factor); break;
    case 'x': calibration_factor -= 1.0;   scale.set_scale(calibration_factor); break;
    case 'd': calibration_factor += 0.1;   scale.set_scale(calibration_factor); break;
    case 'c': calibration_factor -= 0.1;   scale.set_scale(calibration_factor); break;
    case 'T':
      printBoth("Retire o peso e aguarde...");
      delay(2000);
      scale.tare();
      printBoth("Tara concluida.");
      break;
    case 'P':
      printBoth("============================");
      printBoth("calibration_factor = " + String(calibration_factor, 4) + ";");
      printBoth("============================");
      break;
  }
}

void setup() {
  Serial.begin(115200);
  SerialBT.begin("ESP32_Calibracao");
  delay(1000);

  scale.begin(LOADCELL_DOUT_PIN, LOADCELL_SCK_PIN);

  // Aguarda HX711 ficar pronto com timeout de 5 segundos
  printBoth("Aguardando HX711...");
  unsigned long timeout = millis();
  while (!scale.is_ready()) {
    if (millis() - timeout > 5000) {
      printBoth("ERRO: HX711 nao respondeu! Verifique a fiacao (DT=26, SCK=27) e a alimentacao.");
      // Fica em loop imprimindo o erro — nao trava silenciosamente
      while (true) {
        Serial.println("HX711 sem resposta. Verifique conexoes e reinicie.");
        delay(2000);
      }
    }
    delay(10);
  }

  printBoth("HX711 detectado OK.");
  scale.set_scale(calibration_factor);
  scale.tare();

  printBoth("Tara OK. Coloque o peso de referencia.");
  printBoth("[A]/[Z] -> +/- 100");
  printBoth("[a]/[z] -> +/- 10");
  printBoth("[s]/[x] -> +/- 1");
  printBoth("[d]/[c] -> +/- 0.1");
  printBoth("[T]     -> Re-tara");
  printBoth("[P]     -> Imprime fator final");
}

void loop() {
  // Verifica se o HX711 continua respondendo
  if (!scale.is_ready()) {
    Serial.println("AVISO: HX711 nao esta pronto, aguardando...");
    delay(200);
    return;
  }

  float peso = abs(scale.get_units());

  String leitura = "Peso: " + String(peso, 1) + " g  |  Fator: " + String(calibration_factor, 2);
  Serial.println(leitura);
  SerialBT.println(leitura);

  while (Serial.available()) {
    processCommand((char)Serial.read());
  }

  while (SerialBT.available()) {
    processCommand((char)SerialBT.read());
  }

  delay(200);
}

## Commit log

2026-05-08 Docs: align documentation with updated schematic controls
    [Untitled Sketch 2.fzz]
2026-05-08 add imagem do esquematico atualizado
    [Untitled Sketch 2.fzz, teste_estatico.kicad_pcb, teste_estatico.kicad_sch]
2026-05-11 adcionado arquivo para fabricação cnc
    [freerouting.dsn, temp-freerouting.dsn, teste_estatico.kicad_pcb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]
2026-05-11 adcionado atulização nos arquivos de pcb kicad
    [freerouting.dsn, teste_estatico.kicad_pcb]
2026-05-14 atulização nos arquivos de pcb
    [teste_estatico.kicad_pcb, teste_estatico.kicad_sch]
2026-05-16 Atualiza ponteiro do histórico KiCad
2026-05-16 Adiciona arquivo PCB do teste estatico
    [teste_estatico.kicad_pcb]
2026-05-29 feat: adcionado arquivos de fabricação e modificação na pcb
    [teste_estatico.kicad_pcb, teste_estatico.kicad_sch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]
2026-07-09 feat : adcionado codigo para calibração manual do fator de calibração e novos modos no firmware principal
2026-07-09 chore: atualizando a pcb
    [teste_estatico.kicad_pcb, teste_estatico.kicad_sch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]
2026-07-10 feat(firmware): atualizar pinagem para netlist do KiCad
    - LED_PIN: 4 -> 19
    - BUZZER_PIN: 33 -> 32
    - BTN_PIN: 32 -> 33
    - CELULA_DT_PIN: 26 -> 4
    - CELULA_SCK_PIN: 27 -> 18
    - Adicionar SD_SCK_PIN (25), SD_MISO_PIN (23), SD_MOSI_PIN (27)
    [firmware.ino]
2026-07-10 feat(firmware): usar SPI customizado para SD card
    - Adicionar SPIClass spiSD(VSPI) para SCK no GPIO25
    - Inicializar spiSD.begin() com pinos customizados antes de SD.begin()
    - SD.begin() agora recebe a instância spiSD
2026-07-10 feat(firmware): timeout e robustez no setupHX711
    - Timeout de 5s aguardando is_ready() antes de configurar
    - Warmup de 10 leituras descartadas para estabilização
    - tare(10) com média de 10 amostras
    - Retorna false em caso de timeout (tratado no setup)
2026-07-10 feat(firmware): verificar is_ready() antes de ler HX711
    - Guard em logData(): pula leitura se HX711 não estiver pronto
    - Guard no stream de calibração (configMode): só lê se is_ready()
    - Evita leituras de lixo em caso de perda de comunicação
2026-07-10 feat(firmware): adicionar comando GET LOAD FACTOR e log de boot
    - Print do loadFactor carregado do Preferences no boot
    - Novo comando GET LOAD FACTOR para consultar fator sem entrar em configMode
2026-07-10 docs: atualizar pinagem para netlist do KiCad e remover segundo botão
    - Atualizar tabela de conexões em HARDWARE.md (HX711, SD SPI, LED, botão)
    - Remover referências ao botão de novo arquivo (não existe mais)
    - LED: GPIO4 -> GPIO19
    - HX711: DT GPIO26->GPIO4, SCK GPIO27->GPIO18
    - SD SPI: SCK GPIO18->GPIO25, MISO GPIO19->GPIO23, MOSI GPIO23->GPIO27
    - Botão TARE: GPIO32 -> GPIO33
    - Buzzer: GPIO33 -> GPIO32
    - Adicionar GET LOAD FACTOR em API.md e FIRMWARE.md
    - Atualizar BOM: remover segundo botão, adicionar buzzer
2026-07-10 feat(firmware): atualizar loadFactor default para -284.6
    - Trocar valor default de 277306.0 para -284.6 no firmware
    - Atualizar exemplos em FIRMWARE.md e API.md
2026-07-10 feat(firmware): verificar is_ready() antes de tare() nos handlers
    - Botão TARE: ignora se HX711 não estiver pronto
    - INIT CONFIG: avisa e não entra em configMode se HX711 não responder
    - Evita travamento ou leitura de lixo em caso de falha de comunicação
2026-07-10 feat(firmware): enviar boot log e GET LOAD FACTOR via Bluetooth
    - Boot log agora usa printToSerials() para chegar ao BT
    - Resposta de GET LOAD FACTOR idem
2026-07-10 refactor(firmware): remover código morto
    - Remover #include <Wire.h> (não utilizado)
    - Remover variável selectLoop (declarada mas nunca usada)
    - Remover função createDir() (definida mas nunca chamada)
2026-07-10 feat(firmware): aceitar comandos via Bluetooth Serial
    - Extrair lógica de comandos para processCommand()
    - Ler comandos de SerialUSB e SerialBT
    - TARE, GET LOAD FACTOR, INIT CONFIG, SET LOAD FACTOR funcionam por BT
2026-07-10 docs: atualizar para indicar comandos via Bluetooth
    - Bluetooth agora suporta envio de comandos (não só telemetria)
    - Atualizar descrição do protocolo em API.md
    - Atualizar descrição da interface em FIRMWARE.md
2026-07-10 fix: HX711 não respondia no ESP32 (INPUT_PULLUP + wait_ready_timeout)
    - Adicionado INPUT_PULLUP no pino DOUT após escala.begin() para corrigir bug da biblioteca HX711 que usa INPUT no ESP32 (problema do ESP8266)
    - Substituído is_ready() por wait_ready_timeout() no TARE, INIT CONFIG e logData para maior robustez
    - Removida mensagem de AVISO em logData (agora pula silenciosamente)
    - Pressure.h: adicionada média de 10 leituras ADC para reduzir ruído
    - Calibration CLI: aumentado amostras padrão para 200 e adicionado delay antes da leitura
    - Calibration GUI: aumentado amostras padrão para 200
    [Pressure.h, fator_de_calibracao_cli.py, fator_de_calibracao_main.py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]
2026-07-17 feat(firmware): aumentar taxa de amostragem HX711
    - INTERVALO: 500ms → 1ms
    - get_units: 5 → 1 amostra por leitura
    - get_value: 5 → 1 amostra no modo calibração
2026-07-21 fator de calibração manual
2026-07-29 fix(firmware): garantir valor absoluto na leitura de peso da celula de carga
    [firmware.ino]
